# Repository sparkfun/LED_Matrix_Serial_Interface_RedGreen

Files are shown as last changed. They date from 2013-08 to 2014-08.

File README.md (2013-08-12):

LED Matrix Serial Interface-Red/Green
======================================

[LED Matrix-Serial Interface-RG  
*LED Matrix- Serial Interface- Red/Green (COM-00759)*](https://www.sparkfun.com/products/759)

This is a medium sized LED Matrix with a backpack that has been designed to take SPI serial input and display any graphics you pass it.

Repository Contents
-------------------
* **/Firmware** - Firmware that comes installed on the backpack
* **/Hardware** - All Eagle design files (.brd, .sch)

License Information
-------------------
The hardware is released under [Creative Commons Share-alike 3.0](http://creativecommons.org/licenses/by-sa/3.0/).  
All other code is open source so please feel free to do anything you want with it; you buy me a beer if you use this and we meet someday ([Beerware license](http://en.wikipedia.org/wiki/Beerware)).

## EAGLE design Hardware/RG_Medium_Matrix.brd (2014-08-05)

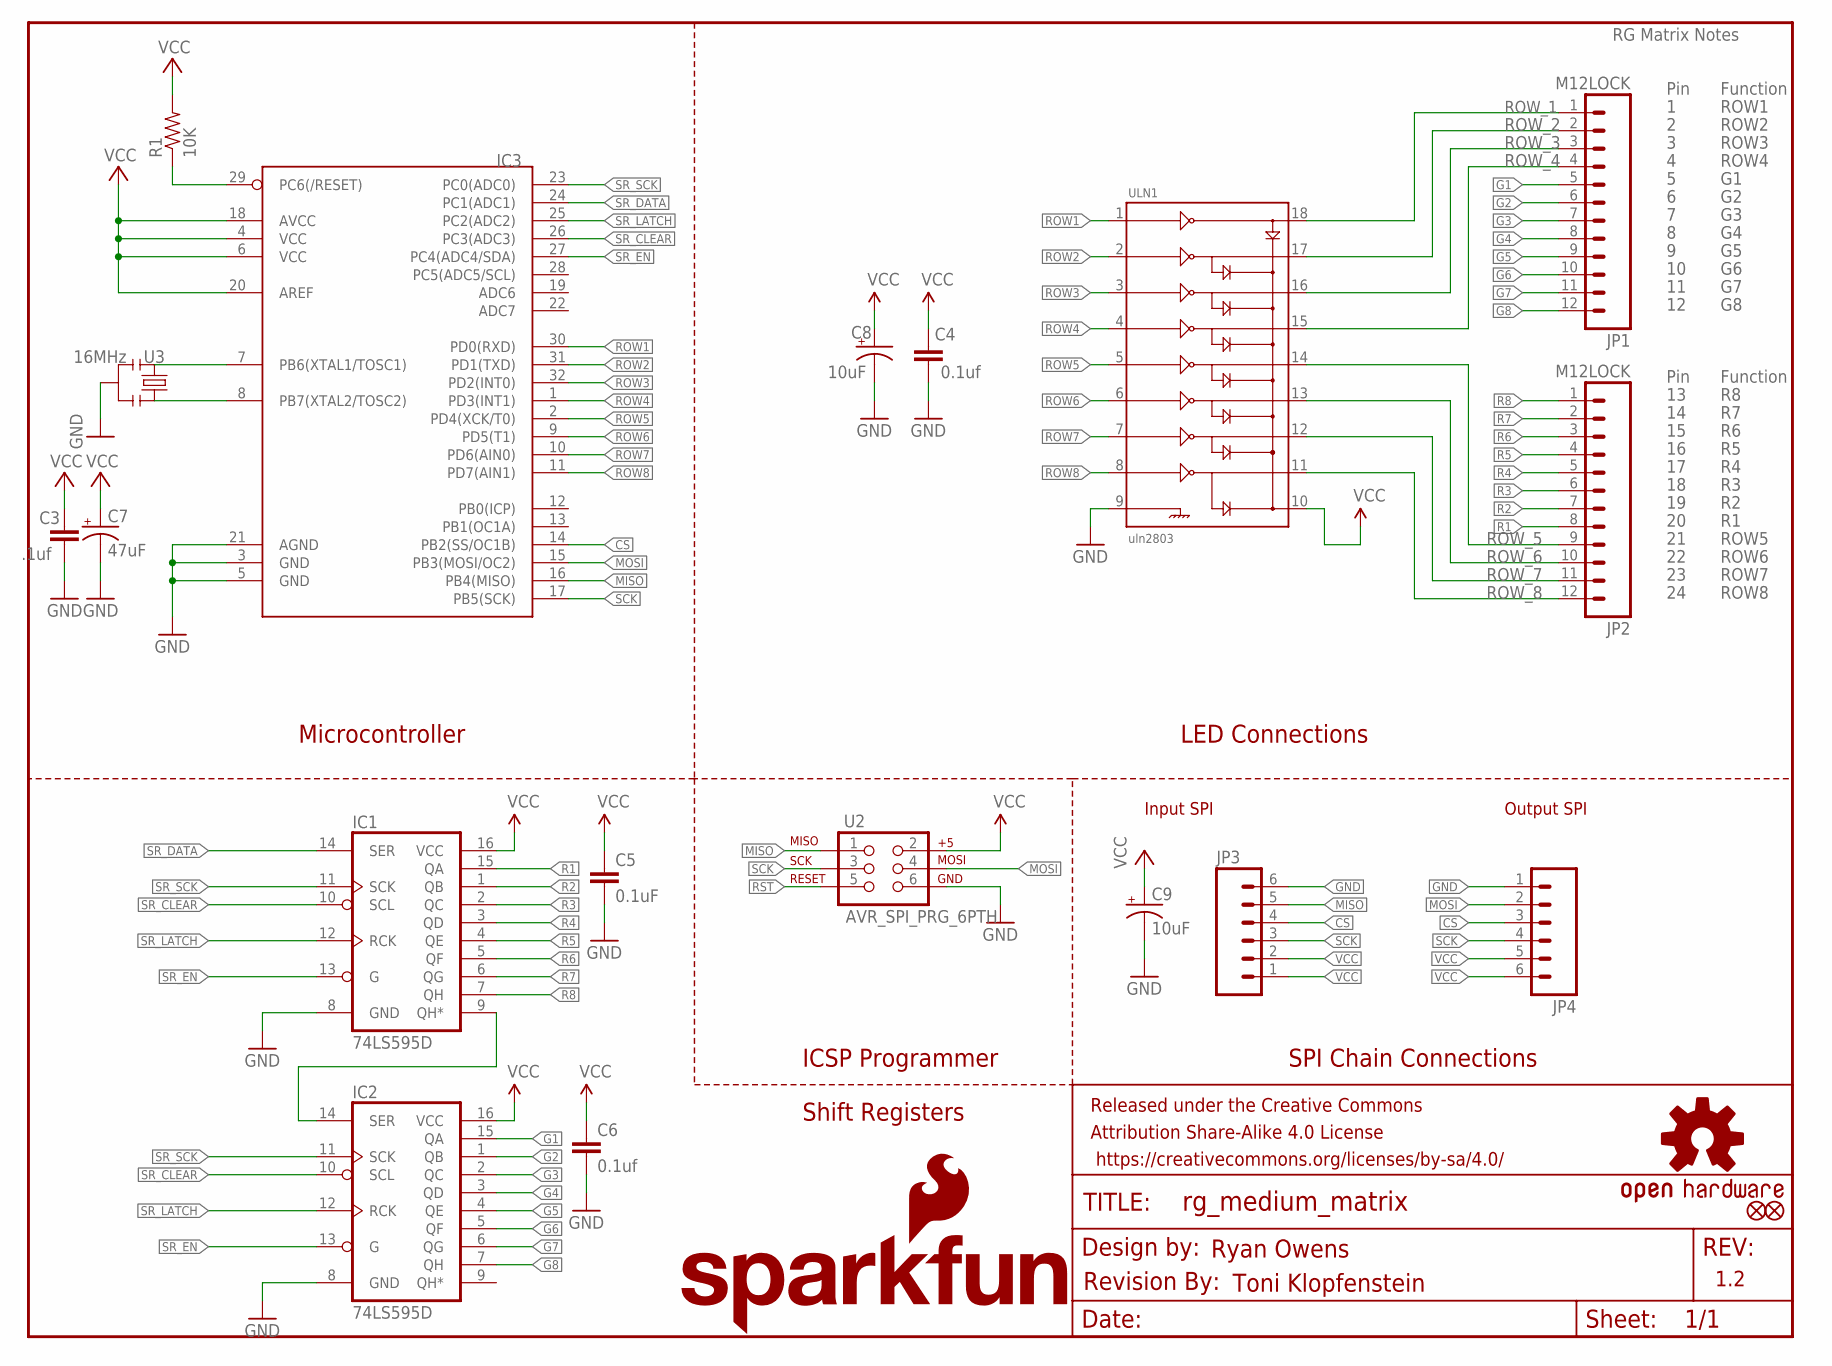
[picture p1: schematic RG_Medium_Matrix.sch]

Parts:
C3: .1uf; 0603-CAP
C4, C6: 0.1uf; 0603-CAP
C5: 0.1uF; 0603-CAP
C7: 47uF; EIA3528
C8, C9: 10uF; EIA3216
FRAME1: FRAME-LETTER; CREATIVE_COMMONS
IC1, IC2: 74LS595D; SO16
IC3: ATMEGA328_SMT; TQFP32-08
JP1, JP2: M12LOCK; 1X12_LOCK
JP3, JP4: M06LOCK; 1X06_LOCK
LOGO1: OSHW-LOGOS; OSHW-LOGO-S
LOGO2: SFE_LOGO_NAME_FLAME.1_INCH; SFE_LOGO_NAME_FLAME_.1
R1: 10K; 0603-RES
U2: AVR_SPI_PRG_6PTH; 2X3
U3: 16MHz; RESONATOR-SMD
U$1, U$3: FIDUCIAL1X2; FIDUCIAL-1X2
U$2: REVISION
ULN1: uln2803; SO18L

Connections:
CS: IC3.14 (PB2(SS/OC1B)), JP3.4, JP4.3
G1: IC2.15 (QA), JP1.5
G2: IC2.1 (QB), JP1.6
G3: IC2.2 (QC), JP1.7
G4: IC2.3 (QD), JP1.8
G5: IC2.4 (QE), JP1.9
G6: IC2.5 (QF), JP1.10
G7: IC2.6 (QG), JP1.11
G8: IC2.7 (QH), JP1.12
GND: C3.2, C4.1, C5.2, C6.2, C7.C (-), C8.C (-), C9.C (-), IC1.8 (GND), IC2.8 (GND), IC3.3 (GND), IC3.5 (GND), IC3.21 (AGND), JP3.6, JP4.1, U2.6, U3.2, ULN1.9
MISO: IC3.16 (PB4(MISO)), JP3.5, U2.1
MOSI: IC3.15 (PB3(MOSI/OC2)), JP4.2, U2.4
unnamed: IC3.7 (PB6(XTAL1/TOSC1)), U3.1
unnamed: IC3.8 (PB7(XTAL2/TOSC2)), U3.3
unnamed: IC1.9 (QH*), IC2.14 (SER)
R1: IC1.15 (QA), JP2.8
R2: IC1.1 (QB), JP2.7
R3: IC1.2 (QC), JP2.6
R4: IC1.3 (QD), JP2.5
R5: IC1.4 (QE), JP2.4
R6: IC1.5 (QF), JP2.3
R7: IC1.6 (QG), JP2.2
R8: IC1.7 (QH), JP2.1
ROW1: IC3.30 (PD0(RXD)), ULN1.1
ROW2: IC3.31 (PD1(TXD)), ULN1.2
ROW3: IC3.32 (PD2(INT0)), ULN1.3
ROW4: IC3.1 (PD3(INT1)), ULN1.4
ROW5: IC3.2 (PD4(XCK/T0)), ULN1.5
ROW6: IC3.9 (PD5(T1)), ULN1.6
ROW7: IC3.10 (PD6(AIN0)), ULN1.7
ROW8: IC3.11 (PD7(AIN1)), ULN1.8
ROW_1: JP1.1, ULN1.18
ROW_2: JP1.2, ULN1.17
ROW_3: JP1.3, ULN1.16
ROW_4: JP1.4, ULN1.15
ROW_5: JP2.9, ULN1.14
ROW_6: JP2.10, ULN1.13
ROW_7: JP2.11, ULN1.12
ROW_8: JP2.12, ULN1.11
RST: IC3.29 (PC6(/RESET)), R1.1, U2.5
SCK: IC3.17 (PB5(SCK)), JP3.3, JP4.4, U2.3
SR_CLEAR: IC1.10 (SCL), IC2.10 (SCL), IC3.26 (PC3(ADC3))
SR_DATA: IC1.14 (SER), IC3.24 (PC1(ADC1))
SR_EN: IC1.13 (G), IC2.13 (G), IC3.27 (PC4(ADC4/SDA))
SR_LATCH: IC1.12 (RCK), IC2.12 (RCK), IC3.25 (PC2(ADC2))
SR_SCK: IC1.11 (SCK), IC2.11 (SCK), IC3.23 (PC0(ADC0))
VCC: C3.1, C4.2, C5.1, C6.1, C7.A (+), C8.A (+), C9.A (+), IC1.16 (VCC), IC2.16 (VCC), IC3.4 (VCC), IC3.6 (VCC), IC3.18 (AVCC), IC3.20 (AREF), JP3.1, JP3.2, JP4.5, JP4.6, R1.2, U2.2, ULN1.10

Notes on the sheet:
1.2
Pin
Function
ROW1
ROW2
ROW3
ROW4
ROW5
ROW6
ROW7
ROW8
RG Matrix Notes
Input SPI
Output SPI
Toni Klopfenstein
Ryan Owens
Microcontroller
LED Connections
ICSP Programmer
Shift Registers
SPI Chain Connections

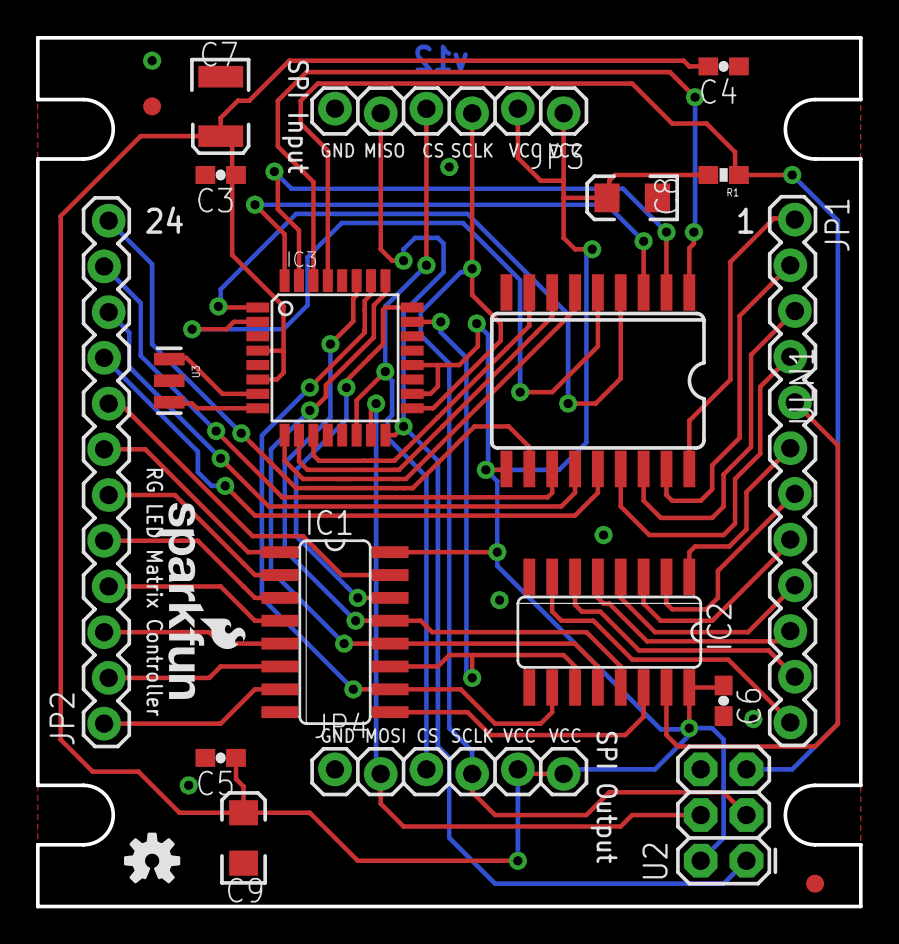
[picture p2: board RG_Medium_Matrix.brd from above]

Board: 2 copper layers, 45.7 x 48.3 mm, 24 parts (0 on the bottom side), 47 nets.

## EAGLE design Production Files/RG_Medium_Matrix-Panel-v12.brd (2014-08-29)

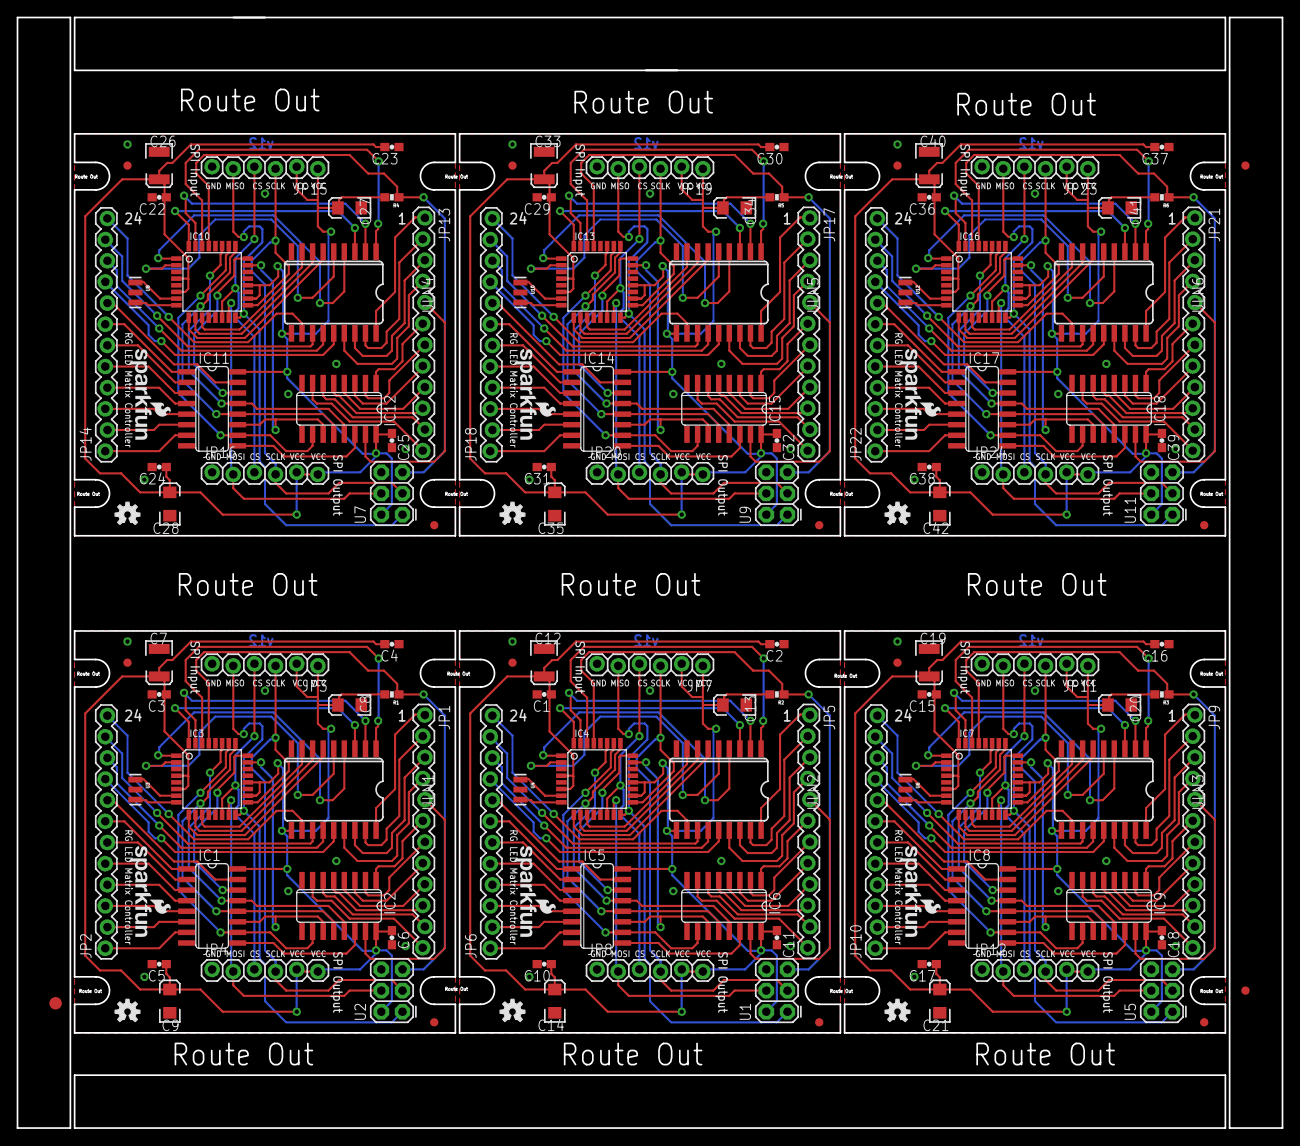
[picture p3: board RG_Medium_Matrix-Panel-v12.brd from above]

Board: 2 copper layers, 151.9 x 133.3 mm, 135 parts (0 on the bottom side), 282 nets.

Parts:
C1, C3, C15, C22, C29, C36: .1uf; 0603-CAP
C2, C4, C6, C11, C16, C18, C23, C25, C30, C32, C37, C39: 0.1uf; 0603-CAP
C5, C10, C17, C24, C31, C38: 0.1uF; 0603-CAP
C7, C12, C19, C26, C33, C40: 47uF; EIA3528
C8, C9, C13, C14, C20, C21, C27, C28, C34, C35, C41, C42: 10uF; EIA3216
E$1: FIDUCIAL-1.5X3
E$3, E$4: FIDUCIAL-1X2
IC1, IC2, IC5, IC6, IC8, IC9, IC11, IC12, IC14, IC15, IC17, IC18: 74LS595D; SO16
IC3, IC4, IC7, IC10, IC13, IC16: TQFP32-08
JP1, JP2, JP5, JP6, JP9, JP10, JP13, JP14, JP17, JP18, JP21, JP22: M12LOCK; 1X12_LOCK
JP3, JP4, JP7, JP8, JP11, JP12, JP15, JP16, JP19, JP20, JP23, JP24: 1X06_LOCK
LOGO1, LOGO3, LOGO5, LOGO7, LOGO9, LOGO11: OSHW-LOGOS; OSHW-LOGO-S
LOGO2, LOGO4, LOGO6, LOGO8, LOGO10, LOGO12: SFE_LOGO_NAME_FLAME.1_INCH; SFE_LOGO_NAME_FLAME_.1
R1, R2, R3, R4, R5, R6: 10K; 0603-RES
U1, U2, U5, U7, U9, U11: AVR_SPI_PRG_6PTH; 2X3
U3, U4, U6, U8, U10, U12: 16MHz; RESONATOR-SMD
U$1, U$2, U$3, U$4, U$5, U$6, U$7, U$8, U$9, U$10, U$11, U$12: FIDUCIAL1X2; FIDUCIAL-1X2
ULN1, ULN2, ULN3, ULN4, ULN5, ULN6: uln2803; SO18L

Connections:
CS: IC3.14, JP3.4, JP4.3
CS1: IC4.14, JP7.4, JP8.3
CS2: IC7.14, JP11.4, JP12.3
CS3: IC10.14, JP15.4, JP16.3
CS4: IC13.14, JP19.4, JP20.3
CS5: IC16.14, JP23.4, JP24.3
G1: IC2.15, JP1.5
G2: IC2.1, JP1.6
G3: IC2.2, JP1.7
G4: IC2.3, JP1.8
G5: IC2.4, JP1.9
G6: IC2.5, JP1.10
G7: IC2.6, JP1.11
G8: IC2.7, JP1.12
G9: IC6.15, JP5.5
G10: IC6.1, JP5.6
G11: IC6.2, JP5.7
G12: IC6.3, JP5.8
G13: IC6.4, JP5.9
G14: IC6.5, JP5.10
G15: IC6.6, JP5.11
G16: IC6.7, JP5.12
G17: IC9.15, JP9.5
G18: IC9.1, JP9.6
G19: IC9.2, JP9.7
G20: IC9.3, JP9.8
G21: IC9.4, JP9.9
G22: IC9.5, JP9.10
G23: IC9.6, JP9.11
G24: IC9.7, JP9.12
G25: IC12.15, JP13.5
G26: IC12.1, JP13.6
G27: IC12.2, JP13.7
G28: IC12.3, JP13.8
G29: IC12.4, JP13.9
G30: IC12.5, JP13.10
G31: IC12.6, JP13.11
G32: IC12.7, JP13.12
G33: IC15.15, JP17.5
G34: IC15.1, JP17.6
G35: IC15.2, JP17.7
G36: IC15.3, JP17.8
G37: IC15.4, JP17.9
G38: IC15.5, JP17.10
G39: IC15.6, JP17.11
G40: IC15.7, JP17.12
G41: IC18.15, JP21.5
G42: IC18.1, JP21.6
G43: IC18.2, JP21.7
G44: IC18.3, JP21.8
G45: IC18.4, JP21.9
G46: IC18.5, JP21.10
G47: IC18.6, JP21.11
G48: IC18.7, JP21.12
GND: C3.2, C4.1, C5.2, C6.2, C7.C, C8.C, C9.C, IC1.8, IC2.8, IC3.3, IC3.5, IC3.21, JP3.6, JP4.1, U2.6, U3.2, ULN1.9
GND1: C1.2, C2.1, C10.2, C11.2, C12.C, C13.C, C14.C, IC4.3, IC4.5, IC4.21, IC5.8, IC6.8, JP7.6, JP8.1, U1.6, U4.2, ULN2.9
GND2: C15.2, C16.1, C17.2, C18.2, C19.C, C20.C, C21.C, IC7.3, IC7.5, IC7.21, IC8.8, IC9.8, JP11.6, JP12.1, U5.6, U6.2, ULN3.9
GND3: C22.2, C23.1, C24.2, C25.2, C26.C, C27.C, C28.C, IC10.3, IC10.5, IC10.21, IC11.8, IC12.8, JP15.6, JP16.1, U7.6, U8.2, ULN4.9
GND4: C29.2, C30.1, C31.2, C32.2, C33.C, C34.C, C35.C, IC13.3, IC13.5, IC13.21, IC14.8, IC15.8, JP19.6, JP20.1, U9.6, U10.2, ULN5.9
GND5: C36.2, C37.1, C38.2, C39.2, C40.C, C41.C, C42.C, IC16.3, IC16.5, IC16.21, IC17.8, IC18.8, JP23.6, JP24.1, U11.6, U12.2, ULN6.9
MISO: IC3.16, JP3.5, U2.1
MISO1: IC4.16, JP7.5, U1.1
MISO2: IC7.16, JP11.5, U5.1
MISO3: IC10.16, JP15.5, U7.1
MISO4: IC13.16, JP19.5, U9.1
MISO5: IC16.16, JP23.5, U11.1
MOSI: IC3.15, JP4.2, U2.4
MOSI1: IC4.15, JP8.2, U1.4
MOSI2: IC7.15, JP12.2, U5.4
MOSI3: IC10.15, JP16.2, U7.4
MOSI4: IC13.15, JP20.2, U9.4
MOSI5: IC16.15, JP24.2, U11.4
unnamed: IC3.7, U3.1
unnamed: IC3.8, U3.3
unnamed: IC5.9, IC6.14
unnamed: IC4.7, U4.1
unnamed: IC4.8, U4.3
unnamed: IC8.9, IC9.14
unnamed: IC7.7, U6.1
unnamed: IC7.8, U6.3
unnamed: IC11.9, IC12.14
unnamed: IC10.7, U8.1
unnamed: IC10.8, U8.3
unnamed: IC14.9, IC15.14
unnamed: IC13.7, U10.1
unnamed: IC13.8, U10.3
unnamed: IC17.9, IC18.14
unnamed: IC16.7, U12.1
unnamed: IC16.8, U12.3
unnamed: IC1.9, IC2.14
R1: IC1.15, JP2.8
R2: IC1.1, JP2.7
R3: IC1.2, JP2.6
R4: IC1.3, JP2.5
R5: IC1.4, JP2.4
R6: IC1.5, JP2.3
R7: IC1.6, JP2.2
R8: IC1.7, JP2.1
R9: IC5.15, JP6.8
R10: IC5.1, JP6.7
R11: IC5.2, JP6.6
R12: IC5.3, JP6.5
R13: IC5.4, JP6.4
R14: IC5.5, JP6.3
R15: IC5.6, JP6.2
R16: IC5.7, JP6.1
R17: IC8.15, JP10.8
R18: IC8.1, JP10.7
R19: IC8.2, JP10.6
R20: IC8.3, JP10.5
R21: IC8.4, JP10.4
R22: IC8.5, JP10.3
R23: IC8.6, JP10.2
R24: IC8.7, JP10.1
R25: IC11.15, JP14.8
R26: IC11.1, JP14.7
R27: IC11.2, JP14.6
R28: IC11.3, JP14.5
R29: IC11.4, JP14.4
R30: IC11.5, JP14.3
R31: IC11.6, JP14.2
R32: IC11.7, JP14.1
R33: IC14.15, JP18.8
R34: IC14.1, JP18.7
R35: IC14.2, JP18.6
R36: IC14.3, JP18.5
R37: IC14.4, JP18.4
R38: IC14.5, JP18.3
R39: IC14.6, JP18.2
R40: IC14.7, JP18.1
R41: IC17.15, JP22.8
R42: IC17.1, JP22.7
R43: IC17.2, JP22.6
R44: IC17.3, JP22.5
R45: IC17.4, JP22.4
R46: IC17.5, JP22.3
R47: IC17.6, JP22.2
R48: IC17.7, JP22.1
ROW1: IC3.30, ULN1.1
ROW2: IC3.31, ULN1.2
ROW3: IC3.32, ULN1.3
ROW4: IC3.1, ULN1.4
ROW5: IC3.2, ULN1.5
ROW6: IC3.9, ULN1.6
ROW7: IC3.10, ULN1.7
ROW8: IC3.11, ULN1.8
ROW9: IC4.30, ULN2.1
ROW10: IC4.31, ULN2.2
ROW11: IC4.32, ULN2.3
ROW12: IC4.1, ULN2.4
ROW13: IC4.2, ULN2.5
ROW14: IC4.9, ULN2.6
ROW15: IC4.10, ULN2.7
ROW16: IC4.11, ULN2.8
ROW17: IC7.30, ULN3.1
ROW18: IC7.31, ULN3.2
ROW19: IC7.32, ULN3.3
ROW20: IC7.1, ULN3.4
ROW21: IC7.2, ULN3.5
ROW22: IC7.9, ULN3.6
ROW23: IC7.10, ULN3.7
ROW24: IC7.11, ULN3.8
ROW25: IC10.30, ULN4.1
ROW26: IC10.31, ULN4.2
ROW27: IC10.32, ULN4.3
ROW28: IC10.1, ULN4.4
ROW29: IC10.2, ULN4.5
ROW30: IC10.9, ULN4.6
ROW31: IC10.10, ULN4.7
ROW32: IC10.11, ULN4.8
ROW33: IC13.30, ULN5.1
ROW34: IC13.31, ULN5.2
ROW35: IC13.32, ULN5.3
ROW36: IC13.1, ULN5.4
ROW37: IC13.2, ULN5.5
ROW38: IC13.9, ULN5.6
ROW39: IC13.10, ULN5.7
ROW40: IC13.11, ULN5.8
ROW41: IC16.30, ULN6.1
ROW42: IC16.31, ULN6.2
ROW43: IC16.32, ULN6.3
ROW44: IC16.1, ULN6.4
ROW45: IC16.2, ULN6.5
ROW46: IC16.9, ULN6.6
ROW47: IC16.10, ULN6.7
ROW48: IC16.11, ULN6.8
ROW_1: JP1.1, ULN1.18
ROW_2: JP1.2, ULN1.17
ROW_3: JP1.3, ULN1.16
ROW_4: JP1.4, ULN1.15
ROW_5: JP2.9, ULN1.14
ROW_6: JP2.10, ULN1.13
ROW_7: JP2.11, ULN1.12
ROW_8: JP2.12, ULN1.11
ROW_9: JP5.1, ULN2.18
ROW_10: JP5.2, ULN2.17
ROW_11: JP5.3, ULN2.16
ROW_12: JP5.4, ULN2.15
ROW_13: JP6.9, ULN2.14
ROW_14: JP6.10, ULN2.13
ROW_15: JP6.11, ULN2.12
ROW_16: JP6.12, ULN2.11
ROW_17: JP9.1, ULN3.18
ROW_18: JP9.2, ULN3.17
ROW_19: JP9.3, ULN3.16
ROW_20: JP9.4, ULN3.15
ROW_21: JP10.9, ULN3.14
ROW_22: JP10.10, ULN3.13
ROW_23: JP10.11, ULN3.12
ROW_24: JP10.12, ULN3.11
ROW_25: JP13.1, ULN4.18
ROW_26: JP13.2, ULN4.17
ROW_27: JP13.3, ULN4.16
ROW_28: JP13.4, ULN4.15
ROW_29: JP14.9, ULN4.14
ROW_30: JP14.10, ULN4.13
ROW_31: JP14.11, ULN4.12
ROW_32: JP14.12, ULN4.11
ROW_33: JP17.1, ULN5.18
ROW_34: JP17.2, ULN5.17
ROW_35: JP17.3, ULN5.16
ROW_36: JP17.4, ULN5.15
ROW_37: JP18.9, ULN5.14
ROW_38: JP18.10, ULN5.13
ROW_39: JP18.11, ULN5.12
ROW_40: JP18.12, ULN5.11
ROW_41: JP21.1, ULN6.18
ROW_42: JP21.2, ULN6.17
ROW_43: JP21.3, ULN6.16
ROW_44: JP21.4, ULN6.15
ROW_45: JP22.9, ULN6.14
ROW_46: JP22.10, ULN6.13
ROW_47: JP22.11, ULN6.12
ROW_48: JP22.12, ULN6.11
RST: IC3.29, R1.1, U2.5
RST1: IC4.29, R2.1, U1.5
RST2: IC7.29, R3.1, U5.5
RST3: IC10.29, R4.1, U7.5
RST4: IC13.29, R5.1, U9.5
RST5: IC16.29, R6.1, U11.5
SCK: IC3.17, JP3.3, JP4.4, U2.3
SCK1: IC4.17, JP7.3, JP8.4, U1.3
SCK2: IC7.17, JP11.3, JP12.4, U5.3
SCK3: IC10.17, JP15.3, JP16.4, U7.3
SCK4: IC13.17, JP19.3, JP20.4, U9.3
SCK5: IC16.17, JP23.3, JP24.4, U11.3
SR_CLEAR: IC1.10, IC2.10, IC3.26
SR_CLEAR1: IC4.26, IC5.10, IC6.10
SR_CLEAR2: IC7.26, IC8.10, IC9.10
SR_CLEAR3: IC10.26, IC11.10, IC12.10
SR_CLEAR4: IC13.26, IC14.10, IC15.10
SR_CLEAR5: IC16.26, IC17.10, IC18.10
SR_DATA: IC1.14, IC3.24
SR_DATA1: IC4.24, IC5.14
SR_DATA2: IC7.24, IC8.14
SR_DATA3: IC10.24, IC11.14
SR_DATA4: IC13.24, IC14.14
SR_DATA5: IC16.24, IC17.14
SR_EN: IC1.13, IC2.13, IC3.27
SR_EN1: IC4.27, IC5.13, IC6.13
SR_EN2: IC7.27, IC8.13, IC9.13
SR_EN3: IC10.27, IC11.13, IC12.13
SR_EN4: IC13.27, IC14.13, IC15.13
SR_EN5: IC16.27, IC17.13, IC18.13
SR_LATCH: IC1.12, IC2.12, IC3.25
SR_LATCH1: IC4.25, IC5.12, IC6.12
SR_LATCH2: IC7.25, IC8.12, IC9.12
SR_LATCH3: IC10.25, IC11.12, IC12.12
SR_LATCH4: IC13.25, IC14.12, IC15.12
SR_LATCH5: IC16.25, IC17.12, IC18.12
SR_SCK: IC1.11, IC2.11, IC3.23
SR_SCK1: IC4.23, IC5.11, IC6.11
SR_SCK2: IC7.23, IC8.11, IC9.11
SR_SCK3: IC10.23, IC11.11, IC12.11
SR_SCK4: IC13.23, IC14.11, IC15.11
SR_SCK5: IC16.23, IC17.11, IC18.11
VCC: C3.1, C4.2, C5.1, C6.1, C7.A, C8.A, C9.A, IC1.16, IC2.16, IC3.4, IC3.6, IC3.18, IC3.20, JP3.1, JP3.2, JP4.5, JP4.6, R1.2, U2.2, ULN1.10
VCC1: C1.1, C2.2, C10.1, C11.1, C12.A, C13.A, C14.A, IC4.4, IC4.6, IC4.18, IC4.20, IC5.16, IC6.16, JP7.1, JP7.2, JP8.5, JP8.6, R2.2, U1.2, ULN2.10
VCC2: C15.1, C16.2, C17.1, C18.1, C19.A, C20.A, C21.A, IC7.4, IC7.6, IC7.18, IC7.20, IC8.16, IC9.16, JP11.1, JP11.2, JP12.5, JP12.6, R3.2, U5.2, ULN3.10
VCC3: C22.1, C23.2, C24.1, C25.1, C26.A, C27.A, C28.A, IC10.4, IC10.6, IC10.18, IC10.20, IC11.16, IC12.16, JP15.1, JP15.2, JP16.5, JP16.6, R4.2, U7.2, ULN4.10
VCC4: C29.1, C30.2, C31.1, C32.1, C33.A, C34.A, C35.A, IC13.4, IC13.6, IC13.18, IC13.20, IC14.16, IC15.16, JP19.1, JP19.2, JP20.5, JP20.6, R5.2, U9.2, ULN5.10
VCC5: C36.1, C37.2, C38.1, C39.1, C40.A, C41.A, C42.A, IC16.4, IC16.6, IC16.18, IC16.20, IC17.16, IC18.16, JP23.1, JP23.2, JP24.5, JP24.6, R6.2, U11.2, ULN6.10

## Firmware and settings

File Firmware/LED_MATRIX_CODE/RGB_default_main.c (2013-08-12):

/*


*/

#include <inttypes.h>
#include <avr/io.h>
#include <avr/interrupt.h>
#include <math.h>

#define sbi(var, mask)   ((var) |= (uint8_t)(1 << mask))
#define cbi(var, mask)   ((var) &= (uint8_t)~(1 << mask))

#define CLK				0
#define CLR				3
#define LATCH			2
#define DATA			1
#define EN				4

volatile uint8_t spiTemp;
volatile uint8_t lineByte[3]; 
volatile uint32_t red[8]; 
volatile uint32_t green[8];
volatile uint32_t blue[8];
volatile uint8_t row;
volatile uint8_t frameBufferIndex;


volatile uint32_t red[] 	= {0x000001, 0x040000, 0x000008, 0x200000, 0x000040, 0x010000, 0x000200, 0x002000}; 
volatile uint32_t green[]	= {0x800000, 0x000004, 0x100000, 0x000020, 0x000080, 0x008000, 0x000400, 0x004000};
volatile uint32_t blue[]	= {0x000002, 0x080000, 0x000010, 0x400000, 0x020000, 0x000100, 0x001000, 0x000800};

volatile uint8_t image[] = {		
  1,  1,  1,  1,  1,  1,  1,  1,
  0,  1,  0,  0,  0,  0,  3,  0,
  0,  0,  1,  0,  0,  3,  0,  0,
  0,  0,  0,  1,  3,  0,  0,  0,
  0,  0,  0,  3,  1,  0,  0,  0,
  0,  0,  3,  0,  0,  1,  0,  0,
  0,  3,  0,  0,  0,  0,  1,  0,
  3,  0,  0,  0,  0,  0,  0,  1,
};

ISR (SIG_SPI) 
{
  if (!(PINB & 0x04))
  {
    spiTemp = SPDR;      			// read spi data register
/*    SPDR = image[(frameBufferIndex+1)%64];      |+ Write SPI Data register +|*/
    SPDR = image[(frameBufferIndex+1)&63];
    image[frameBufferIndex] = spiTemp;		// load value to frame buffer
    frameBufferIndex++;				// increment frame buffer index (pixel number)
/*    frameBufferIndex %= 64;			// wrap at 64*/
    frameBufferIndex &= 63;
  }
}


void delay_ms(uint16_t x);					// general purpose delay

void ioinit (void);						// initializes IO

// this is the function that shifts 16 bits out to the 74hc595 shift registers
// it is inlined to speed things up
void inline shiftLine(volatile uint8_t[], volatile uint8_t rowNum);

int main (void)
{
  uint8_t i;
  uint32_t line;

  ioinit ();

  SPCR = (1 << SPE) | (1 << SPIE);
  sei();

  cbi(PORTC, CLR);
  delay_ms(1);
  sbi(PORTC, CLR);
  cbi(PORTC, EN);

  row = 0;
  PORTD = 0;

  for (i = 0; i < 64; i++)
    image[i] = 0;

  frameBufferIndex = 6;
  i = 0;

  lineByte[0] = 0xff;
  lineByte[1] = 0xff;
  lineByte[2] = 0xff;

  for (row = 0; row < 8; row++){
    shiftLine(lineByte, row);
    delay_ms(700);
  }

  for (row = 0; row < 8; row++){
    shiftLine(lineByte, row);
    delay_ms(700);
  }


  for (row = 0; row < 8; row++){
    shiftLine(lineByte, row);
    delay_ms(700);
  }

  for (;;){	//LED_off;

    // check cs status, reset frame buffer index to 0 if set

    if (PINB & 0x04)
      frameBufferIndex = 0;

    for (row = 0; row < 8; row++){
      line = 0;
      for (i = 0; i < 8; i++){

        switch (image[i + (8 * row)]){
          case 0: line |= 0; break;
          case 1: line |= red[i]; break;
          case 2: line |= green[i]; break;
          case 3: line |= blue[i]; break; 
          case 4: line |= (red[i] | green[i]); break;
          case 5: line |= (green[i] | blue[i]); break;
          case 6: line |= (blue[i] | red[i]); break; 
          case 7: line |= (red[i] | green[i] | blue[i]); break;
        }
        //line |= red[i];
      }
      lineByte[0] = line;
      lineByte[1] = line >> 8;
      lineByte[2] = line >> 16;
      shiftLine(lineByte, row);
    }
  }
  return (0);
}

void ioinit (void) /* Note [5] */
{
  DDRB |= (1 << 4);
  DDRD = 0xFF;  // atmega8 LEDs
  PORTD = 0x01;
  DDRC = 0x1F;
  sbi(PORTC, CLK);
  sbi(PORTC, CLR);
  sbi(PORTC, DATA);
  sbi(PORTC, LATCH);
  sbi(PORTC, EN);
}

void inline shiftLine(volatile uint8_t byte[], volatile uint8_t rowNum){
  uint8_t i, j;

  cbi(PORTC, LATCH);
  //sbi(PORTC, EN);
  for (j = 0; j < 3; j++){
    for(i = 0; i < 8; i++){

      cbi(PORTC, CLK);
      if (byte[j] & (1 << i))
        sbi(PORTC, DATA);
      else
        cbi(PORTC, DATA);

      sbi(PORTC, CLK);

    }
  }

  sbi(PORTC, EN);
  sbi(PORTC, LATCH);
  PORTD = (1 << rowNum);//(1 << rowMap[rowNum]);
  cbi(PORTC, EN);
}

//General short delays
void delay_ms(uint16_t x)
{
  uint8_t y, z;
  for ( ; x > 0 ; x--){
    for ( y = 0 ; y < 4 ; y++){
      for ( z = 0 ; z < 40 ; z++){
        asm volatile ("nop");
      }


    }
  }
}

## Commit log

2013-08-12 Initial file commit
    [RG_Medium_Matrix-v11.brd, RG_Medium_Matrix-v11.sch]
2014-05-16 Updating to V_1.2- 0603 packages, trace cleaning
    [RG_Medium_Matrix-v11.brd, RG_Medium_Matrix-v11.sch, RG_Medium_Matrix.brd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]
2014-05-19 Updating to locking footprints for SPI connectors
    [RG_Medium_Matrix.brd, RG_Medium_Matrix.sch]
2014-05-19 Switching to locking fp for 12 pin headers
    [RG_Medium_Matrix.brd, RG_Medium_Matrix.sch]
2014-07-03 created panel v12
    [RG_Medium_Matrix-Panel-v12.brd]
2014-08-05 Moving female header in to reduce gap between screens
    [RG_Medium_Matrix.brd]
2014-08-05 Final update
    [RG_Medium_Matrix.brd]
2014-08-08 re-created panel v12
    [RG_Medium_Matrix-Panel-v12.brd]
2014-08-29 re-re-created panel v12
    this panel has proper spacing for male and female headers
    [RG_Medium_Matrix-Panel-v12.brd]

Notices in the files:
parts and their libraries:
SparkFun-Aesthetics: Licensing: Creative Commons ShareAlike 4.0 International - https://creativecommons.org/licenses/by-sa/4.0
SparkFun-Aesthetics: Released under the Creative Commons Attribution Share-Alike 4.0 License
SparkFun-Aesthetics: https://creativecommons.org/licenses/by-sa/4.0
